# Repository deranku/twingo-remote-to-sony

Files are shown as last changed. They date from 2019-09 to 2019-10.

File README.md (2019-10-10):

# Twingo Phase II steering wheel to Sony HU

My Twingo steering wheel remote did not go along with the new Sony MEX-N5300BT radio. But since it is a very handy gimmick and seemingly all new radios have tiny ugly buttons, I built an adapter to connect the two. Here's how:

## Resources
For the remote to arduino and the code part, my approach is heavily based on [this Reddit post](https://www.reddit.com/r/diyelectronics/comments/413liz/renault_steering_wheel_remote_to_jvc/) by Bart Kuijper, who Built an adapter for his JVC radio. He also drew a [schematic](https://imgur.com/vg5zvh5) and wrote a nice [arduino sketch](https://pastebin.com/fXbScxV4). JVC uses some sort of simple digital protocol, while Sony (and Pioneer) radios listen to resistances. Certain resistances trigger functions on the radio. For the resistances, there is a [nice post](http://jvde.net/comment/150) on jvde.net describing how Sony/Pioneer radios are controlled by resistance ladders.  
It seems that all base functions/resistances work the same across Sony and Pioneer, while anything phone specific (call/reject/voice control) does not. Trial and error..

## Remote to Arduino and power
The remote is solely connected through a male Mini-ISO plug (yellow), which fits in the factory radio. For testing, the remote can be removed from the car with a few screws. I removed it eventually, it saved a lot of times running to the car. I got a female Mini-ISO plug from ebay which connects the  remote to Arduino.  
The Arduino is powered via USB from a cigarette lighter socket to USB adapter. I used a cable with a right-angled USB-A plug that leads to the ashtray and down the console to the Arduino (if you remove the ashtray, you can lead the cable into the console and then hook the ashtray back in again).  
This way, you don't have to mingle with the car electrics and the whole operation can be removed without traces. Also, no need to worry about surges, a step down converter, etc. I stuffed everything in the console, around the radio there is enough room. 

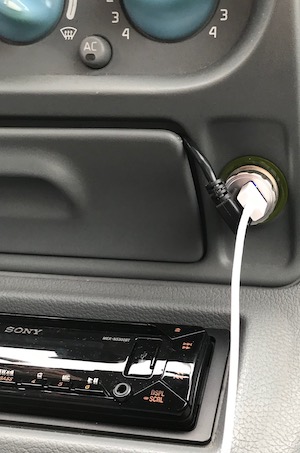
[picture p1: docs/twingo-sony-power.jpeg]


## Arduino to radio
I used 5V reed relays to open the circuit between tip/ring and sleeve/ring of the 3,5mm headphone jack that goes to the radio. Each relay is connected to a resistor for it's corresponding function. My first thought was to use optocouplers, but their inner resistance that also varies with temperature would complicate things. My radio uses a voltage of 3,3V between tip and ring (older models seem to use 5V), which leaves not much space to match the correct resistance that is needed to trigger a function. Those relays are relatively expensive (~2€ each), but they feature very low level of inner resistance and are fun to work with. I started a discussion about the right choice of components [here](https://www.mikrocontroller.net/topic/479725#new) (german). Also, have a look on the post and especially the comments in the JVDE post mentioned above about the resistance values.

### Code
The Arduino sketch is straightforward and well documented. Here is my setup:

| BUTTON | ARDUINO PIN| RESISTOR | HU FUNCTION |
|:--|:--|:--|:--|
| top left | A0 | 1,2k | standby/off |
| top right | A5 | Tip + Ring | voice control |
| bottom | A2 | 2,2K | source |
| vol + | A3 | 15K | vol + |
| mute | A1 | 4,7K | mute |
| vol - | A4 | 22K | vol - |
| wheel up | D10 | 5,6k + Ring | radio: preset + |
| wheel dn | D11 | 8,2k + Ring | radio: preset - |

Note that voice control only needs tip and ring connected to sleeve, there's no resistor for this function (found out by accident).

## Schematic and circuit
This is my circuit (not the final version). Have a look at the schematics and the PCB view of the Fritzing file. The circuit is a good base to start soldering, although I had to leave more space between the relays.  
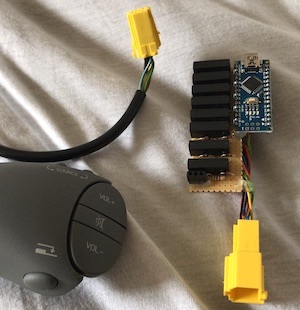
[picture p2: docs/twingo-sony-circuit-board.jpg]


As you can see in the PCB, the circuits to the Arduino are not routed. This is just for readability, I hand-soldered anyways.

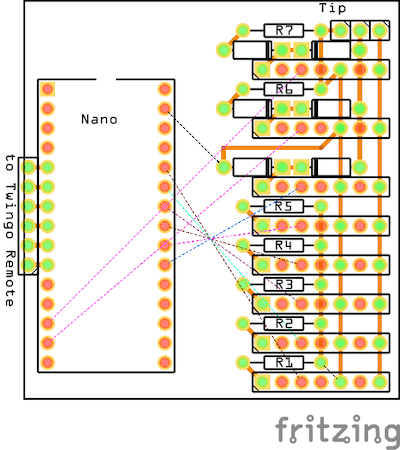
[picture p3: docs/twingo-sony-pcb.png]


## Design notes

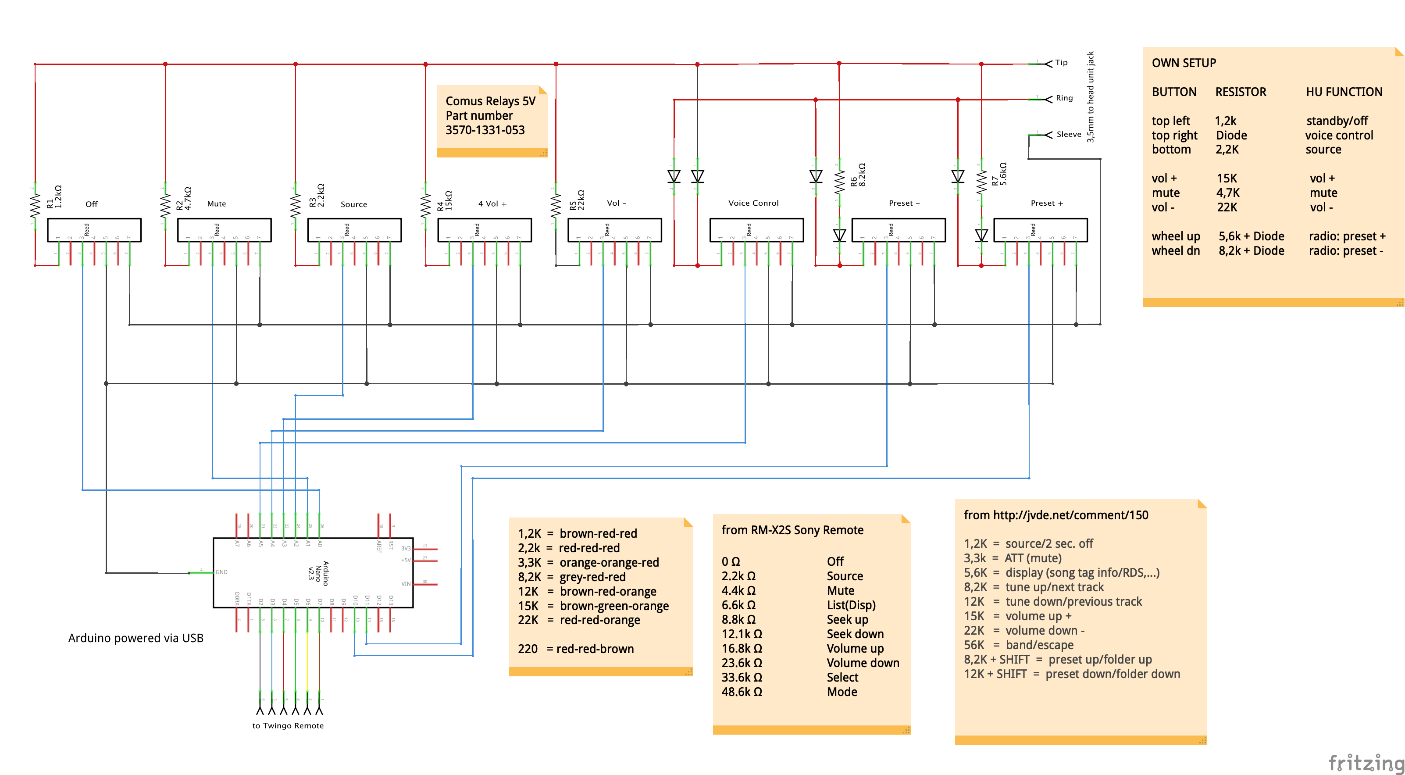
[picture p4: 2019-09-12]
schematic/twingo-sony-schematic.png

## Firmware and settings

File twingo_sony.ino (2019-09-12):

// https://www.reddit.com/r/diyelectronics/comments/413liz/renault_steering_wheel_remote_to_jvc/
// https://youtu.be/fk73SCOE8qU
// https://pastebin.com/fXbScxV4


// Renault Twingo / Clio steering wheel remote wire functions

// pin_cycle_current  1     0              2
//         OUTPUTS    BLUE  GREEN          YELLOW
// INPUTS  PIN#       3     5              6

// BLACK   2          MUTE  TOP RIGHT BTN  TOP LEFT BTN
// RED     4          VOL+  BOTTOM BTN     VOL-

//                    HIGH  HIGH           LOW    SCROLL UP (CCW)
// BROWN   7          HIGH  LOW            HIGH  SCROLLWHEEL
//                    LOW   HIGH           HIGH   SCROLL DN (CW)

// Outputs are set LOW one at a time (the other outputs will be HIGH). Inputs (with internal pull-up) are then evaluated.
//   If an input is being pulled LOW this means a button is being pressed. Taking into account which output is currently LOW
//   we know which button this is. For example, is output pin 3 (Blue wire) is currently LOW and we also read LOW on
//   input pin 2 (Black) we know the MUTE button is being pressed.
// For the scrollwheel we must take into account its last known position in order to determine if there has been a change.
// We can determine the direction based on which pins are being pulled LOW.

// Connect Renault Twingo / Clio steering wheel remote wires to these pins
#define BLACKPIN    2 // D2
#define BLUEPIN     3 // D3
#define REDPIN      4 // D4
#define GREENPIN    5 // D5
#define YELLOWPIN   6 // D6
#define BROWNPIN    7 // D7

// Connect reed relays to these pins

#define OFF_PIN         14
#define MUTE_PIN        15
#define SOURCE_PIN      16
#define VOL_UP_PIN      17
#define VOL_DN_PIN      18
#define SIRI_PIN        19
#define PRESET_UP_PIN   10
#define PRESET_DN_PIN   11

// On-board LED, useful for debugging
#define LEDPIN     13 // D13

// Set number of output pins and put those pins in an array to cycle through when polling the input pins
#define OUT_PINS 3
unsigned char out_pins[OUT_PINS] = {GREENPIN, BLUEPIN, YELLOWPIN};

// Duration in ms for sending input from the scrollwheel
const unsigned int wheel_send_dur = 50;

// While any button is active, the corresponding pins are not set LOW
bool button_active = false;


void setup() {

  Serial.begin(115200);

  // Set the proper pins as output
  pinMode(OFF_PIN, OUTPUT);
  pinMode(MUTE_PIN, OUTPUT);
  pinMode(SOURCE_PIN, OUTPUT);
  pinMode(VOL_UP_PIN, OUTPUT);
  pinMode(VOL_DN_PIN, OUTPUT);
  pinMode(SIRI_PIN, OUTPUT);
  pinMode(PRESET_UP_PIN, OUTPUT);
  pinMode(PRESET_DN_PIN, OUTPUT);

  // Output LOW to make sure optocouplers are off
  digitalWrite(OFF_PIN, LOW);
  digitalWrite(MUTE_PIN, LOW);
  digitalWrite(SOURCE_PIN, LOW);
  digitalWrite(VOL_UP_PIN, LOW);
  digitalWrite(VOL_DN_PIN, LOW);
  digitalWrite(SIRI_PIN, LOW);
  digitalWrite(PRESET_UP_PIN, LOW);
  digitalWrite(PRESET_DN_PIN, LOW);

  // Set the pins connected to the steering wheel remote as input / output
  pinMode(BLACKPIN, INPUT_PULLUP);
  pinMode(BLUEPIN, OUTPUT);
  pinMode(REDPIN, INPUT_PULLUP);
  pinMode(GREENPIN, OUTPUT);
  pinMode(YELLOWPIN, OUTPUT);
  pinMode(BROWNPIN, INPUT_PULLUP);

  pinMode(LEDPIN, OUTPUT);                  // Set pin connected to on-board LED as output...
  digitalWrite(LEDPIN, LOW);                // ...and turn LED off
}




// The steering wheel remote has 6 buttons and a scrollwheel, interfaced via 6 wires.
// This function will cycle through the output pins, setting one pin LOW at a time.
// It will then poll the input pins to see which input pins - if any - are pulled LOW.
void loop() {

  // To keep track of which output pin is currently LOW
  static unsigned char pin_cycle_current = 0;
  // To store the last known scrollwheel position
  static unsigned char pin_cycle_stored;

  // Only cycle through pins for scrollwheel, if no button is currently pressed
  if(!button_active){
  
    // After booting, there is no known last position for the scrollwheel
    // So on the first poll of the scrollwheel just store the current position and don't send a command
    static boolean first_run = true;
    unsigned char i;
  
    // Reset pin_cycle_current counter after last pin
    if (++pin_cycle_current > (OUT_PINS - 1)) pin_cycle_current = 0;     
  
    // Cycle through the output pins, setting one of them LOW and the rest HIGH
    for (i = 0; i < OUT_PINS; i++) {                                     
      if (i == pin_cycle_current)
        digitalWrite(out_pins[i], LOW);
      else
        digitalWrite(out_pins[i], HIGH);
    }
  
  
    // Scrollwheel
    // We're only interested if this pin is being pulled LOW
    if (!digitalRead(BROWNPIN)) {

      if (pin_cycle_current != pin_cycle_stored) {
      // If the output that's currently LOW is different from the one that was LOW the last time
      //  we came through here, then the scrollwheel has changed position
  
        // Result of this calculation can range from -2 to 2
        signed char scrollwheel_current = pin_cycle_current - pin_cycle_stored; 
        // Store which output pin is currently LOW
        pin_cycle_stored = pin_cycle_current;                            
        // If this is the first run, don't send a command
        if (first_run) {                                                 
          //   (since there was no previously known scrollwheel position)
          first_run = false;                                             
          return;
        }
        if ((scrollwheel_current == 1) || (scrollwheel_current == -2)) { 
          // If above calculation resulted in 1 or -2 the scrollwheel was rotated down (cw)
  
          Serial.println("                        Scroll wheel DOWN");
          digitalWrite(PRESET_UP_PIN, HIGH);
          digitalWrite(LEDPIN, HIGH);
          delay(wheel_send_dur);
          digitalWrite(PRESET_UP_PIN, LOW);
          digitalWrite(LEDPIN, LOW);
        }else {                                                          
          // If above calculation resulted in anything else the scrollwheel was rotated up (ccw)
  
          Serial.println("                        Scroll wheel UP");
          digitalWrite(PRESET_DN_PIN, HIGH);
          digitalWrite(LEDPIN, HIGH);
          delay(wheel_send_dur);
          digitalWrite(PRESET_DN_PIN, LOW);
          digitalWrite(LEDPIN, LOW);
        }
      }
    }
  }

  // We're only interested if this pin is being pulled LOW
  if (!digitalRead(REDPIN)) {   

    if(!digitalRead(GREENPIN)){
      // RED (input) is LOW while GREEN (output) is LOW
      // BOTTOM button pressed
      Serial.println("                        Bottom button pressed");
      digitalWrite(SOURCE_PIN, HIGH);
      digitalWrite(LEDPIN, HIGH);
      button_active = true;
    }
    else if(!digitalRead(BLUEPIN)){
      // RED (input) is LOW while BLUE (output) is LOW
      // VOLUME + button pressed
      Serial.println("                        Vol + button pressed");
      digitalWrite(VOL_UP_PIN, HIGH);
      digitalWrite(LEDPIN, HIGH);
      button_active = true;
    }
    else if(!digitalRead(YELLOWPIN)){
        // RED (input) is LOW while YELLOW (output) is LOW:
        // VOLUME - button pressed
      Serial.println("                        Vol - button pressed");
      digitalWrite(VOL_DN_PIN, HIGH);
      digitalWrite(LEDPIN, HIGH);
      button_active = true;
    }
  }

  // We're only interested if this pin is being pulled LOW
  else if (!digitalRead(BLACKPIN)) { 

    if(!digitalRead(GREENPIN)){
      // BLACK (input) is LOW while GREEN (output) is LOW
      // TOP RIGHT button is pressed
      Serial.println("                        Top right button pressed");
      digitalWrite(SIRI_PIN, HIGH);
      digitalWrite(LEDPIN, HIGH);
      button_active = true;
    }
    else if(!digitalRead(BLUEPIN)){
      // BLACK (input) is LOW while BLUE (output) is LOW
      // MUTE button is pressed
      Serial.println("                        Mute button pressed");
      digitalWrite(MUTE_PIN, HIGH);
      digitalWrite(LEDPIN, HIGH);
      button_active = true;
    }
    else if(!digitalRead(YELLOWPIN)){
      // BLACK (input) is LOW while YELLOW (output) is LOW
      // TOP LEFT button is pressed
      Serial.println("                        Top left button pressed");
      digitalWrite(OFF_PIN, HIGH);
      digitalWrite(LEDPIN, HIGH);
      button_active = true;
    }
  }
  else{
    // No button pressed
    // Serial.println("NO buttons pressed");
    button_active = false;
  }


  if(!button_active) {
    digitalWrite(OFF_PIN, LOW);
    digitalWrite(MUTE_PIN, LOW);
    digitalWrite(SOURCE_PIN, LOW);
    digitalWrite(VOL_UP_PIN, LOW);
    digitalWrite(VOL_DN_PIN, LOW);
    digitalWrite(SIRI_PIN, LOW);
    digitalWrite(PRESET_UP_PIN, LOW);
    digitalWrite(PRESET_DN_PIN, LOW);
    digitalWrite(LEDPIN, LOW);
  }

}
